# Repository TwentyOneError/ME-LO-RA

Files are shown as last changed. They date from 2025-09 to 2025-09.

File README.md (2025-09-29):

<div align="center">
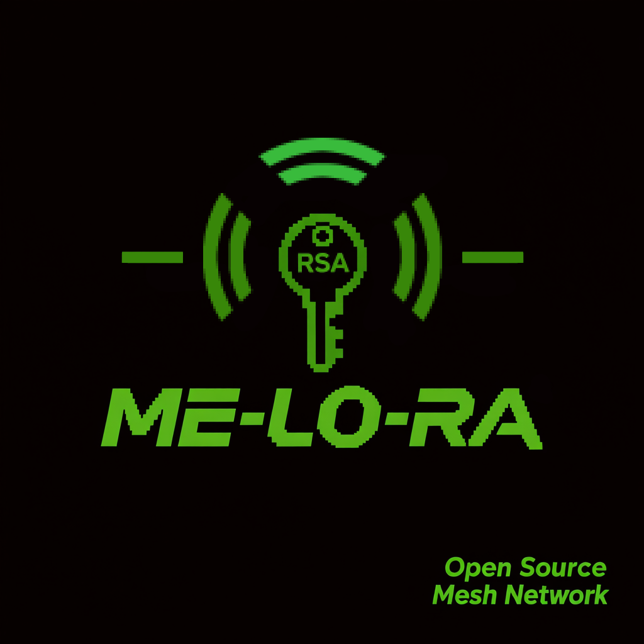
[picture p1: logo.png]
ME-LO-RA Logo
  
  <h1>ME-LO-RA NETWORK</h1>
  <p><em>An anonymous mesh network for secure radio-based messaging</em></p>
</div>

---

## 📌 Table of Contents

- [What is it?](#-what-is-it)
- [Why is it needed?](#-why-is-it-needed)
- [Project foundation](#-project-foundation)
- [How does it work?](#-how-does-it-work)
- [Security and encryption](#-security-and-encryption)
- [Technical limitations](#-technical-limitations)
- [What do you need to get started?](#-what-do-you-need-to-get-started)
- [Wiring diagram](#-wiring-diagram)
- [Modifications and customization](#-modifications-and-customization)
- [Key generation](#-key-generation)
- [Power supply and enclosure](#-power-supply-and-enclosure)
- [Background](#-background)
- [Important!](#-important)
- [Feedback](#-feedback)

---

## ❓ What is it?

**ME-LO-RA NETWORK** is a mesh network based on the **ESP32** microcontroller and **LoRa (SX1278)** radio module, designed for transmitting text messages between users over radio using:

- **RSA** asymmetric encryption,
- **SHA-256**-based digital signatures,
- Message delivery confirmation.

---

## 🛡️ Why is it needed?

This project enables **secure and anonymous** messaging when traditional communication channels are unavailable or disrupted (e.g., during mobile internet outages).

---

## ⚙️ Project foundation

- **Microcontroller**: ESP32  
- **Radio module**: LoRa SX1278  
- **Additional components**: OLED display, button.

---

## 🔄 How does it work?

- The ESP32 creates a Wi-Fi access point and hosts a web interface for sending/receiving messages.
- All messages are encrypted using **RSA** and digitally signed; message integrity is verified via **SHA-256**.
- The recipient validates the signature and decrypts the message.
- A **signed acknowledgment message** is sent back to confirm delivery, preventing third parties from spoofing receipt.
- The network operates on a **mesh** principle: messages can be relayed through intermediate nodes.

---

## 🔐 Security and encryption

- **Any RSA key length** is supported, but due to ESP32 performance constraints, **64–128 bits** are recommended.
- An additional security measure is a **limited and shuffled character set**. This set can be modified, but must be **synchronized among all chat participants** (not required for relaying).
- Public keys and aliases are broadcast publicly (e.g., via the ME-LO-RA broadcast channel).
- No network participant knows the true identity of the sender—only the recipient’s alias is visible.
- For enhanced security, it is recommended to remove all debugging output (e.g., `Serial.print` and `Serial.println`).

> ⚠️ **Warning**: Without synchronized character sets and ordering, message decryption between users will fail. It is recommended to leave these settings unchanged.

---

## 📏 Technical limitations

| Environment | Range |
|---|---|
| Dense urban area | ~500 m |
| Forest | ~1,000 m |
| Line-of-sight | up to 5,000 m |

- **Number of relays**: unlimited.

---

## 🚀 What do you need to get started?

1. Assembled device based on ESP32 + LoRa SX1278.
2. A unique **alias** (nickname). If aliases collide, messages from others will appear corrupted and unreadable.
3. A generated **RSA key pair** (public and private).
4. Exchange your **public key** and **alias** via a public channel (e.g., ME-LO-RA broadcast).

> The more network participants know your public key and alias, the more effective mesh relaying becomes.

---

## 🔌 Wiring diagram

> ⚠️ **Caution**: The shown ESP32 power supply schematic is **not recommended**. Use at your own risk!

> ✅ **Recommendation**: Power the ESP32 via the **5V/VIN** pin using a boost converter to 5 V. If unavailable, connect the battery directly to **5V/VIN**. In this case, the controller will shut down at ~3.9 V battery voltage but will not be damaged.

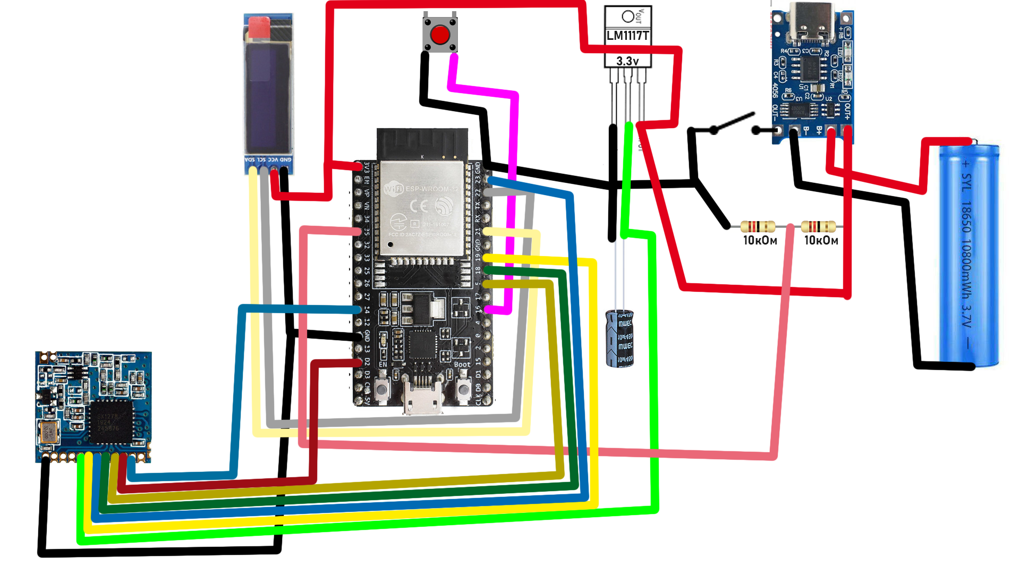
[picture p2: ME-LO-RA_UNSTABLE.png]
Wiring Diagram


### LoRa SX1278

| ESP32 | LoRa SX1278 |
|---|---|
| GND | GND |
| D5 | NSS |
| D2 | DIO0 |
| D18 | SCK |
| D19 | MISO |
| D23 | MOSI |
| D14 | RST |

> ⚠️ **Never power** the LoRa module from the ESP32’s built-in **3.3V regulator**, as this may damage the controller.

### OLED

| ESP32 | OLED |
|---|---|
| 3.3V  | VCC  |
| GND | GND  |
| D22 | SCL  |
| D21 | SDA  |

### Button

| ESP32 | Button |
|---|---|
| D16 | Contact 1 |
| GND | Contact 2 |

- **D35** – pin for measuring battery charge level, connected via a voltage divider as shown in the diagram. Higher-value resistors (e.g., 50 kΩ) may be used.

---

## 🎨 Modifications and customization

The project is easily adaptable to your needs:
- The web interface can be fully customized (styles, logic, etc.).
- Just ensure the **POST request structure** to the ESP32 remains unchanged.

---

## 🔑 Key generation

A Python script is included in the repository to generate RSA keys using prime numbers up to **31 bits**.  
Finding large primes is computationally intensive, so simplified primality tests may be used.

---

## 🔋 Power supply and enclosure

- The enclosure is designed for through-hole mounting (a compact PCB version is planned) and uses a **18650 battery** as the power source.
- A **3D model of the enclosure** is included in the repository—you can 3D-print it.
- Screws used: **M5 × 12 mm**. To install them, insert or press nuts into the corresponding slots in the enclosure.
- Before installing the ESP32 into the enclosure, it’s recommended to add an internal duplicate **"Boot" button** for convenient firmware updates.

---

## 📜 Background

The idea emerged during widespread mobile internet outages in Russia.  
ME-LO-RA is a response to the need for an **independent, anonymous, and secure** messaging system during digital “shutdowns.”

---

## ⚠️ Important!

This project is developed **by a single person** and is provided **“as is.”** Use it **entirely at your own risk**.

---

## 📬 Feedback

- **Email**: [ourmail20210422@gmail.com](mailto:ourmail20210422@gmail.com)
- **Telegram**: [@TO_21_21](https://t.me/TO_21_21)

---

> 🌐 *ME-LO-RA NETWORK – communication freedom without intermediaries.*

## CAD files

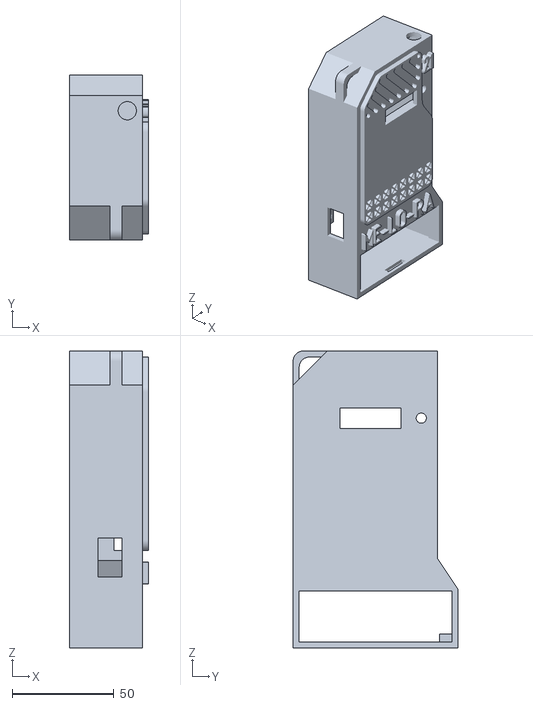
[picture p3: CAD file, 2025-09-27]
Корпус/корпус.stl
39.0 x 81.0 x 146.0

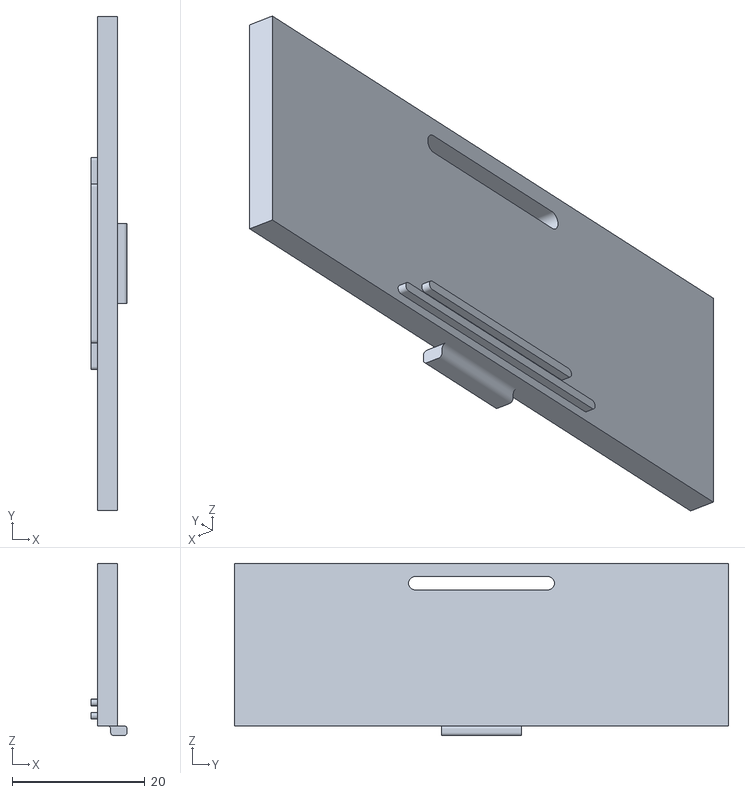
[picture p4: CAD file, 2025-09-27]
Корпус/крышка аккумулятора.stl
5.50 x 74.5 x 26.0

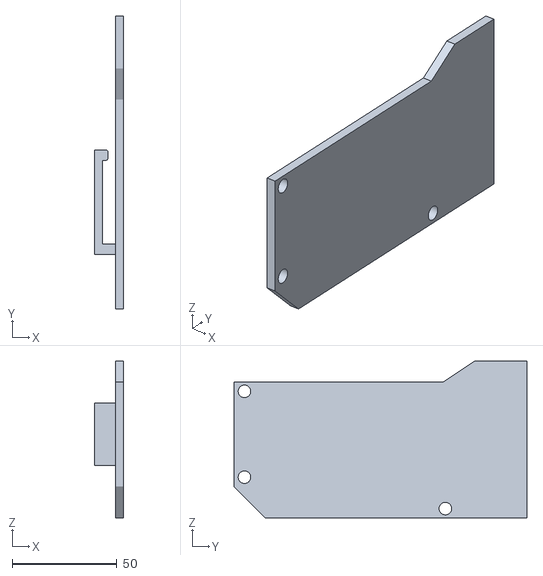
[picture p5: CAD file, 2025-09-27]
Корпус/Задняя крышка.stl
14.0 x 140.0 x 75.0

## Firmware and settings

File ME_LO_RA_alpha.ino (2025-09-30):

#include <SPIFFS.h>
#include "Bigint.cpp"
#include <WiFi.h>
#include <WebServer.h>
#include <Wire.h>
#include <Adafruit_GFX.h>
#include <Adafruit_SSD1306.h>
#include <SPI.h>
#include <LoRa.h>
#include "sha256.h"
#include "html_content.cpp"
#define SCREEN_WIDTH 128
#define SCREEN_HEIGHT 32
#define OLED_RESET     -1
#define BUTTON_PIN 16
#define BATTERY_PIN 35
#define SS_PIN 5
#define RST_PIN 14
#define DIO0_PIN 2
#define PACKET_SIZE 50                         // Размер пакетов в байтах
Adafruit_SSD1306 display(SCREEN_WIDTH, SCREEN_HEIGHT, &Wire, OLED_RESET);
const char* ssid = "ME_LO_RA_AP";              //название вашей Wi-Fi сети
const char* password = "password_1";           //пароль от сети



//----------------------------Костыли для исправления е*****о String в arduino---------

//функция определения длины символа UTF-8
int getUtf8CharSize(byte firstByte) {
  if ((firstByte & 0x80) == 0x00) return 1;      // 1-byte ASCII
  if ((firstByte & 0xE0) == 0xC0) return 2;      // 2-byte character
  if ((firstByte & 0xF0) == 0xE0) return 3;      // 3-byte character
  if ((firstByte & 0xF8) == 0xF0) return 4;      // 4-byte character
  return 1; // Default to 1 byte (invalid marker, but safe)
}

//Функция получения количества символов (не байтов)
unsigned int utf8_strlen(const String &str) {
  unsigned int charCount = 0;
  for (unsigned int i = 0; i < str.length();) {
    i += getUtf8CharSize(str[i]);
    charCount++;
  }
  return charCount;
}

//функция получения символа по индексу
String utf8_charAt(const String &str, unsigned int charIndex) {
  unsigned int currentChar = 0;
  unsigned int byteIndex = 0;
  while (byteIndex < str.length() && currentChar <= charIndex) {
    int charSize = getUtf8CharSize(str[byteIndex]);
    if (currentChar == charIndex) {
      return str.substring(byteIndex, byteIndex + charSize);
    }
    byteIndex += charSize;
    currentChar++;
  }
  return String(); //возвращаем пустую строку при неверном индексе
}
// Функция преобразования символьного индекса в байтовый
unsigned int utf8_charIndexToByteIndex(const String &str, unsigned int charIndex) {
  unsigned int currentChar = 0;
  unsigned int byteIndex = 0;
  while (byteIndex < str.length() && currentChar < charIndex) {
    byteIndex += getUtf8CharSize(str[byteIndex]);
    currentChar++;
  }
  return byteIndex;
}

//Функция поиска подстроки с возвратом символьного индекса
int utf8_indexOf(const String &str, const String &substr, unsigned int startCharIndex = 0) {
  // преобразуем стартовый символьный индекс в байтовый
  unsigned int startByteIndex = utf8_charIndexToByteIndex(str, startCharIndex);
  //стандартный поиск в байтах
  int byteIndex = str.indexOf(substr, startByteIndex);
  //подстрока не найдена
  if (byteIndex == -1) return -1;
  //преобразуем байтовый индекс позиции в символьный
  unsigned int charCount = 0;
  unsigned int currentByteIndex = 0;
  while (currentByteIndex < (unsigned int)byteIndex) {
    currentByteIndex += getUtf8CharSize(str[currentByteIndex]);
    charCount++;
  }
  // проверка корректности позиции
  if (currentByteIndex != (unsigned int)byteIndex) {
    // найденная позиция не совпадает с границей символа
    // продолжаем поиск с следующего символа
    return utf8_indexOf(str, substr, charCount + 1);
  }
  return charCount;
}

// функция для проверки корректности UTF-8 символа в позиции
bool isUtf8CharStart(const String &str, unsigned int byteIndex) {
  if (byteIndex >= str.length()) return false;
  // первый байт никогда не является продолжением
  if (byteIndex == 0) return true;
  // проверяем, что предыдущий байт не является частью мультибайтового символа
  byte prev = str[byteIndex - 1];
  return (prev & 0xC0) != 0x80; //не является continuation byte
}

int countOccurrences(const String& text, const String& search) {
  int count = 0;
  int pos = 0;
  while ((pos = text.indexOf(search, pos)) != -1) {
    count++;
    pos += search.length();
  }
  return count;
}
//----------------------------------------------Вернемся к коду---------------------------------





WebServer server(80);                        // Создание сервера на порту 80


                                             // используемый алфавит
String alphabet = "~`o❆☼☀ФТ;💥?☁🌥УН☔🌀🌗🌓♻x⛱PA]🌡{С🌑🤔🍁⛄э⌚еш⚠Ь🌕⛅х¢⛈🌠€ьЖ🦇wЦ}🔎(Ч⏳.2😘G🐻🌤н🦈🕗🐽Ы🐍🐊🐔VЭ🐀 °🌚⭐🌟💣c🐖|🐄й🐷f❎ЮH🦊🌦£🐉XЙ❌uFZ🐕🌧D🐧✉Kо🌪🐈)3[:💀LlЁЯв📈щ^rд⌛s☺✍®ы🗝☝☟М🌩hQз🍿ЛЩОт❗%🍒а☞☹☻😁😂😃😆😇😈😉😊😋😌😍😎😏😐😒🚤😓😔😖😘😚😜😝😞😠😡😢😣😥😨😩😪😫😭😰🌏🍀😱😲😳😵😶😷😸😹😺😻😼😽😾😿🙀🙅🙆🙇🙈🙉🙊🙋🙌🙍🙎✋🐲👀🐝💢☘☐☒✇✎▁▂▃▄▅▆▇█░▒▓𝌴∫∮∲∳∆∇≤≥≈√∀∃∄∅∈∉∋∌∏∐∑✌∞©🐾💋👣✆🚗☠🚀🙏☢☣🚃🚄🚅🚇🚉🚌🚏🚑🚒🚓🚕😄😅🚙🚚🚢JК&8✅9с☜❓яП☑-m,⚡0🤙И💪O🐳W☮n🖤кЪч💰жД🔒jvёa@🥇у😤g§_❤б6фz+🍋З🍬pdT©🛒Nki🍄CХb🍓/RMБ☯>иEB!юe4t☭рГ💕$гI🔱ъмЕл📹<пА🎁=Y*qUВ#📊y1цШ57РS🔥🎃👻";
String alphab = "~`o;?xPA]{w}(.2GVc|fHXuFZDK)3[:Ll^rshQ%J&89-m,0OWnjva@g_6z+pdTNkiCbRM>EB!e4t$I<=Y*qU#y157S";// однобайтовые символы для кодирования (кроме служебных)
String htmlContent = "";
String user_name = "";
BigInt e_exp = 0;
BigInt module = 0;
BigInt d_exp = 0;
BigInt ue_exp = 0;
BigInt umodule = 0;
std::vector<String> aluser;
std::vector<BigInt> almodule;
std::vector<BigInt> ale_exp;
std::vector<std::vector<String>> mess;
std::vector<std::vector<boolean>> sended;
boolean logged = false;
int button = 0;
int lastb = HIGH;
boolean wifib = true;
int charge = 0;
int ssi = 0;
int snrv = 0;
unsigned long mil = 0;
String last_chckm = "";
String last_mess = "";
int last_usid = -1;
unsigned long last_mil = 0;
std::vector<String> last_m;
std::vector<int> last_id;
String incoming_str = "";
unsigned long incoming_mil = 0;






void setup() {
  pinMode(BUTTON_PIN, INPUT_PULLUP);
  Serial.begin(115200);
  if (!display.begin(SSD1306_SWITCHCAPVCC, 0x3C)) {
    Serial.println("Дисплей не обнаружен");
  }
  display.clearDisplay();
                                              // Инициализация SPIFFS (пока не используется)
  if (!SPIFFS.begin(true)) {
    Serial.println("Ошибка при монтировании SPIFFS");
  }
  // Включение точки доступа Wi-Fi
  WiFi.softAP(ssid, password);
  Serial.print("Включение Wi-Fi");
  Serial.print("AP IP: ");
  Serial.println(WiFi.softAPIP());

  // Регистрация обработчиков:
  server.on("/styles.css", cssstyle);         // css
  server.on("/", registration);               // Регистрация
  server.onNotFound(registration);            // Обработка неизвестных URL (до регистрации)
  server.on("/registration", HTTP_POST, obr); // получение регистрационных данных, добавление друзей
  server.begin();                             // Запуск сервера
  display.setCursor(0, 0);
  display.setTextSize(2);
  display.setTextColor(WHITE);
  display.println("Log in!");
  display.display();
  display.startscrolldiagright(0x00, 0x0F);
  LoRa.setPins(SS_PIN, RST_PIN, DIO0_PIN);
  if (!LoRa.begin(433E6)) {
    display.stopscroll();
    display.clearDisplay();
    Serial.println("Starting LoRa failed!");
    display.setCursor(0, 0);
    display.setTextSize(1);
    display.setTextColor(WHITE);
    display.println("LoRa Fatal Error!");
    display.display();
    while (1);
  }
  while (logged == false){
    server.handleClient();                    // Обработка входящих запросов
  }
  display.stopscroll();
  display.clearDisplay();
  server.onNotFound(handleNotFound);          // Обработка неизвестных URL
  server.on("/messenger", messenger);         // Главная страница
  server.on("/dialogue", dialogue);           // Диалог
  server.on("/add", HTTP_POST, los);          // Добавление абонентов
  server.on("/settings", HTTP_POST, settings);// Параметры
  Serial.println("HTTP сервер запущен");
  aluser.push_back("ALL");                    // Инициализация данных диалогов
  almodule.push_back(512);
  ale_exp.push_back(1);
  mess.push_back(std::vector<String>());
  sended.push_back(std::vector<boolean>());
  mess[0].push_back("Здесь сообщения без шифрования для всех участников сети!");
  sended[0].push_back(false);
  LoRa.setTxPower(20);
  LoRa.setSpreadingFactor(12);
  LoRa.setSyncWord(0x21);
  LoRa.setSignalBandwidth(125E3);
  redraw_display(wifib);
  mil = millis();
  LoRa.onReceive(onReceive);
  LoRa.receive();
}


//--------------------------------------------Отправка сообщений--------------------------------------------------
void SendMess(String messag_e, BigInt modules, BigInt e_exps, unsigned int recipient, bool resend = false){
  String cr = "";
  String chckm = "";
  if(resend==false){
    display.clearDisplay();
    display.setCursor(0, 0);
    display.setTextSize(1);
    display.println("encrypting...");
    display.display();
    display.startscrolldiagright(0x00, 0x0F);
    randomSeed(millis()); 
    chckm = String(random(1000));
    cr = codeRSA(messag_e + "/ " + codeRSA("Y", d_exp, module) + "/ " + user_name, e_exps, modules);// Пока подпись, мягко говоря, слабовата и уязвима для фальсификации, в будущем планирую сделать более хитрую подпись.
    cr = aluser[recipient] + "/ " + chckm + "/ " + cr + "/ " + SHA256::hash(aluser[recipient] + "/ " + chckm + "/ " + cr) + "/ ";
    display.stopscroll();
    display.clearDisplay();
  }else{
    cr = messag_e;
    unsigned int last_z = utf8_indexOf(messag_e,"/ ");
    for(int i = last_z+2; i < utf8_indexOf(messag_e,"/ ",last_z+1);i++){
      chckm += utf8_charAt(messag_e,i);
    }
  }
  Serial.println(cr);
  display.clearDisplay();
  display.setCursor(0, 0);
  display.setTextSize(1);
  display.println("sending...");
  display.display();
  display.startscrolldiagright(0x00, 0x0F);
  bool sende = true;
  int c_try = 0;
  while (sende){
    for (int i = 0;i <= utf8_strlen(cr)/PACKET_SIZE; i++){
      while (LoRa.beginPacket() == 0) {
        Serial.print("waiting for radio ... ");
        delay(100);
      }
      LoRa.beginPacket();
      for (int j=0;j < PACKET_SIZE;j++){
        if (i*PACKET_SIZE+j < utf8_strlen(cr)){
          String s_ = utf8_charAt(cr,i*PACKET_SIZE+j);
          if (s_.length() > 1){
            LoRa.print(s_);
          }else{
            LoRa.write(s_[0]);
          }
        }
      }
      LoRa.endPacket();
      delay(500);
    }
    display.stopscroll();
    display.clearDisplay();
    display.clearDisplay();
    display.setCursor(0, 0);
    display.setTextSize(1);
    display.println("listening...");
    display.display();
    display.startscrolldiagright(0x00, 0x0F);
    mil = millis();
    while (millis()-mil<cr.length()/PACKET_SIZE*1000+11000){
      LoRa.receive();
      if (LoRa.parsePacket()>0){
        Serial.println("Got respond...");
        String s_ = "";
        while (LoRa.available()) {
          s_ += (char)LoRa.read();
        }
        s_ = decodeRSA(s_,e_exps,modules);
        if (s_==chckm){
          Serial.println("success");
          sende = false;
          if (resend){
            last_m.pop_back();
            last_id.pop_back();
          }
        }
      }
      incoming_str = "";
    }
    display.stopscroll();
    display.clearDisplay();
    display.setCursor(0, 0);
    display.setTextSize(1);
    if (c_try == 2){
      if (resend==false){
        last_m.push_back(cr);
        last_id.push_back(recipient);
        last_mil = millis();
      }
      display.stopscroll();
      display.clearDisplay();
      display.setCursor(0, 0);
      display.setTextSize(1);
      mil = 0;
      return;
    }
    display.println("sending...");
    display.display();
    display.startscrolldiagright(0x00, 0x0F);
    c_try++;
  }
  mil = 0;
  display.stopscroll();
  display.clearDisplay();
  display.setCursor(0, 0);
  display.setTextSize(1);
}

void loop() {
  server.handleClient();                      // Обработка входящих запросов веб-клиента
  button = digitalRead(BUTTON_PIN);
  if (millis()-mil>30000){
    mil = millis();
    redraw_display(wifib);
  }
  if(lastb == LOW && button == HIGH){
    mil = millis();
    wifib = !wifib;
    redraw_display(wifib);
  }
  lastb = button;
  LoRa.receive();
  if ((incoming_str.length()>0)and(millis()-incoming_mil>5000)){
    checkIncoming(incoming_str);
    incoming_str = "";
    incoming_mil = millis();
  }
}


void onReceive(int packetSize){//Обработка получаемых пакетов
  if (packetSize == 0) return;
  String incoming = "";
  while (LoRa.available()) {
    incoming += (char)LoRa.read();
  }
  incoming_str += incoming;
  incoming_mil = millis();
  Serial.print("recieved 1 packet with size:");
  Serial.println(packetSize);
}


void checkIncoming(String incoming){// Обработка полученного сообщения
  Serial.println("check...");
  display.clearDisplay();
  display.setCursor(0, 0);
  display.setTextSize(1);
  display.println("Recieving?");
  display.display();
  display.startscrolldiagright(0x00, 0x0F);
  Serial.println(incoming);
  if (utf8_indexOf(incoming,user_name)>=0){
    Serial.println("found for me");
    if (countOccurrences(incoming,"/ ")<4){
      if (countOccurrences(incoming,"/ ")==0){
        if (last_usid > -1){
          if (decodeRSA(incoming,ale_exp[last_usid],almodule[last_usid])==last_chckm){
            while (LoRa.beginPacket() == 0) {
              Serial.print("waiting for radio ... ");
              delay(100);
            }
            LoRa.beginPacket();
            LoRa.print(incoming);
            LoRa.endPacket(true);
          }
        }
      }else{
        Serial.println("bad message (not full)");
        display.stopscroll();
        display.clearDisplay();
        display.setCursor(0, 0);
        display.setTextSize(1);
        return;
      }
    }else{
      Serial.print("Correct syntax");
      unsigned int last_z = utf8_indexOf(incoming,"/ ");
      String chckm = "";
      for(int i = last_z+2; i < utf8_indexOf(incoming,"/ ",last_z+1);i++){
        chckm += utf8_charAt(incoming,i);
      }
      String cr = "";
      last_z = utf8_indexOf(incoming,"/ ",last_z+1);
      for(int i = last_z+2; i < utf8_indexOf(incoming,"/ ",last_z+1);i++){
        cr += utf8_charAt(incoming,i);
      }
      String summ256 = "";
      last_z = utf8_indexOf(incoming,"/ ",last_z+1);
      for(int i = last_z+2; i < utf8_indexOf(incoming,"/ ",last_z+1);i++){
        summ256 += utf8_charAt(incoming,i);
      }
      Serial.println("checking summ");
      if (SHA256::hash(user_name + "/ " + chckm + "/ " + cr) == summ256){
        Serial.print("Summ ok");
        while (LoRa.beginPacket() == 0) {
          Serial.print("waiting for radio ... ");
          delay(100);
        }
        String confirm = codeRSA(chckm,d_exp,module);
        for(int i = 0;i<3;i++){
          LoRa.beginPacket();
          LoRa.print(confirm);
          LoRa.endPacket();
          delay(500);
        }
        if (last_chckm == chckm){
          Serial.println("message dublicate");
        }else{
          last_chckm = chckm;
          last_mess = "";
          last_usid = -1;
          String cr_ = decodeRSA(cr,d_exp,module) + "/ ";
          last_z = utf8_indexOf(cr_,"/ ");
          String messag_e = "";
          for(int i = 0; i < last_z; i++){
            messag_e += utf8_charAt(cr_,i);
          }
          String Y_ = "";
          for(int i = last_z+2; i < utf8_indexOf(cr_,"/ ",last_z+1); i++){
            Y_ += utf8_charAt(cr_,i);
          }
          last_z = utf8_indexOf(cr_,"/ ",last_z+1);
          String sender = "";
          for(int i = last_z+2; i < utf8_indexOf(cr_,"/ ",last_z+1); i++){
            sender += utf8_charAt(cr_,i);
          }
          int u = -1;
          for (int i = 0; i < aluser.size(); i++) {
            if (aluser[i] == sender) {
              u = i;
              break;
            }
          }
          if (u == -1) {
            display.stopscroll();
            display.clearDisplay();
            display.setCursor(0, 0);
            display.setTextSize(1);
            return;
          }else{
            if (decodeRSA(Y_,ale_exp[u],almodule[u])=="Y"){
              Serial.print("Message verification ok");
              mess[u].push_back(messag_e);
              sended[u].push_back(false);
            }
          }
        }
      }
    }
  }else if((utf8_indexOf(incoming,"ALL")>=0)and(countOccurrences(incoming,"/ ")==3)){
    unsigned int last_z = utf8_indexOf(incoming,"/ ");
    String messag_e = "";
    for(int i = last_z+2; i < utf8_indexOf(incoming,"/ ",last_z+1);i++){
      messag_e += utf8_charAt(incoming,i);
    }
    last_z = utf8_indexOf(incoming,"/ ",last_z+1);
    String summ256 = "";
    for(int i = last_z+2; i < utf8_indexOf(incoming,"/ ",last_z+1);i++){
      summ256 += utf8_charAt(incoming,i);
    }
    if(SHA256::hash(messag_e) == summ256){
      int u_u = mess[0].size();
      bool flg = false;
      for (int i = u_u-1;i>-1;i--){
        if(mess[0][i]==messag_e){
          flg = true;
          break;
        }
      }
      if(flg==false){
        mess[0].push_back(messag_e);
        sended[0].push_back(false);
        allsen(messag_e);
      }
    }
  }else if(countOccurrences(incoming,"/ ")<4){
    String recipient  = "";
    for(int i = 0; i < utf8_indexOf(incoming,"/ ");i++){
      recipient += utf8_charAt(incoming,i);
    }
    int u = -1;
    for (int i = 0; i < aluser.size(); i++) {
      if (aluser[i] == recipient) {
        u = i;
        break;
      }
    }
    if (u == -1) {
      Serial.println("undefined user");
      display.stopscroll();
      display.clearDisplay();
      display.setCursor(0, 0);
      display.setTextSize(1);
      return;
    }else{
      unsigned int last_z = utf8_indexOf(incoming,"/ ");
      String chckm = "";
      for(int i = last_z+2; i < utf8_indexOf(incoming,"/ ",last_z+1);i++){
        chckm += utf8_charAt(incoming,i);
      }
      String cr = "";
      last_z = utf8_indexOf(incoming,"/ ",last_z+1);
      for(int i = last_z+2; i < utf8_indexOf(incoming,"/ ",last_z+1);i++){
        cr += utf8_charAt(incoming,i);
      }
      String summ256 = "";
      last_z = utf8_indexOf(incoming,"/ ",last_z+1);
      for(int i = last_z+2; i < utf8_indexOf(incoming,"/ ",last_z+1);i++){
        summ256 += utf8_charAt(incoming,i);
      }
      if (SHA256::hash(recipient + "/ " + chckm + "/ " + cr) == summ256){
        last_chckm = chckm;
        last_mess = incoming;
        last_usid = u;
        for (int i = 0;i <= utf8_strlen(incoming)/PACKET_SIZE; i++){
          while (LoRa.beginPacket() == 0) {
            Serial.print("waiting for radio ... ");
            server.handleClient();
            delay(100);
          }
          LoRa.beginPacket();
          for (int j=0;j < PACKET_SIZE;j++){
            if (i*PACKET_SIZE+j < utf8_strlen(incoming)){
              String s_ = utf8_charAt(incoming,i*PACKET_SIZE+j);
              if (s_.length() == 2){
                LoRa.write(s_[0]);
                LoRa.write(s_[1]);
              }else{
                LoRa.write(s_[0]);
              }
            }
          }
          LoRa.endPacket(true);
        }
      }
    }
  }
  display.stopscroll();
  display.clearDisplay();
  mil = 0;
}





void allsen(String cr){// --------------------------широковещательные сообщения без шифровния.
  display.clearDisplay();
  display.setCursor(0, 0);
  display.setTextSize(1);
  display.println("sending...");
  display.display();
  display.startscrolldiagright(0x00, 0x0F);
  cr = "ALL/ " + cr + "/ " + SHA256::hash(cr);
  for (int i_ = 0;i_ < 3;i_++){ 
    for (int i = 0;i <= utf8_strlen(cr)/PACKET_SIZE; i++){
      while (LoRa.beginPacket() == 0) {
        Serial.print("waiting for radio ... ");
        delay(100);
      }
      LoRa.beginPacket();
      for (int j=0;j < PACKET_SIZE;j++){
        if (i*PACKET_SIZE+j < utf8_strlen(cr)){
          String s_ = utf8_charAt(cr,i*PACKET_SIZE+j);
          if (s_.length() > 1){
            LoRa.print(s_);
          }else{
            LoRa.write(s_[0]);
          }
        }
      }
      LoRa.endPacket();
      delay(500);
    }
  }
  display.stopscroll();
  display.clearDisplay();
  display.setCursor(0, 0);
  display.setTextSize(1);
}
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
